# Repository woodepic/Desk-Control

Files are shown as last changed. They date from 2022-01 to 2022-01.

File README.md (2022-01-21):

# Desk-Control

This is a re-upload of an older project, as I didn't use github at the time. This project spanned July 2020 - August 2020. I am happy to report that it is still working perfectly to this day! (January 2022)

I personally don't enjoy having any form of light when I try to sleep. This would normally mean that I need to unplug my digital clock, monitors, etc on my desk. This causes wear on connectors, is time consuming, and certainly not elegant. To solve this problem, I created a simple relay-based PCB to toggle power on/off for various devices on my desk, and I use a simple button interface to control this. 

I also utilized an arduino to allow for smart control logic of the buttons, backlights, and relay timing. "Smart" features include a fade on/off animation in the buttons' backlights, minimum time between toggles (to allow devices to fully boot before power is cut to them), and more. The PCB uses transistor-switched 12v power to allow for a PWM signal to control the buttons' backlights, optocouplers for relay isolation protection, as well as a basic power supply. 

See below for images of the project. The far right button toggles the clock, and the middle button toggles the in-desk touch monitor:

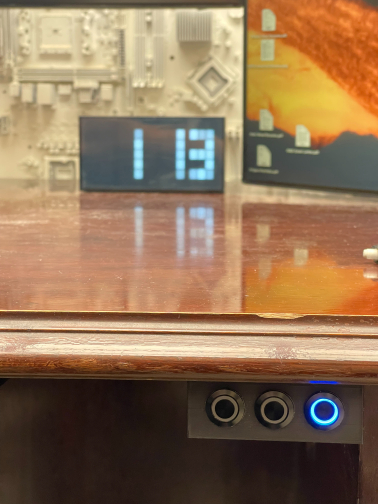
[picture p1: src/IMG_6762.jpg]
Button 3 toggles clock
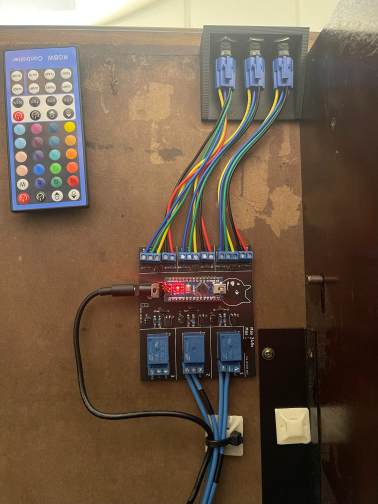
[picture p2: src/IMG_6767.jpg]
Underside view of buttons & PCB
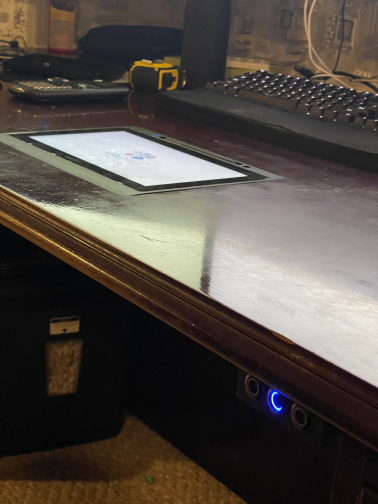
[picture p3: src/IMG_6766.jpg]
Button 2 toggles in-desk touch monitor


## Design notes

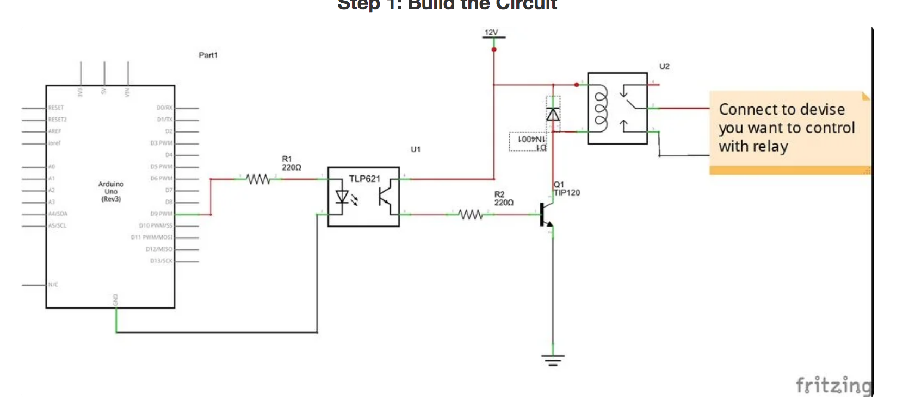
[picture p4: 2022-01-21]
PCB/Relays/Schematic.png

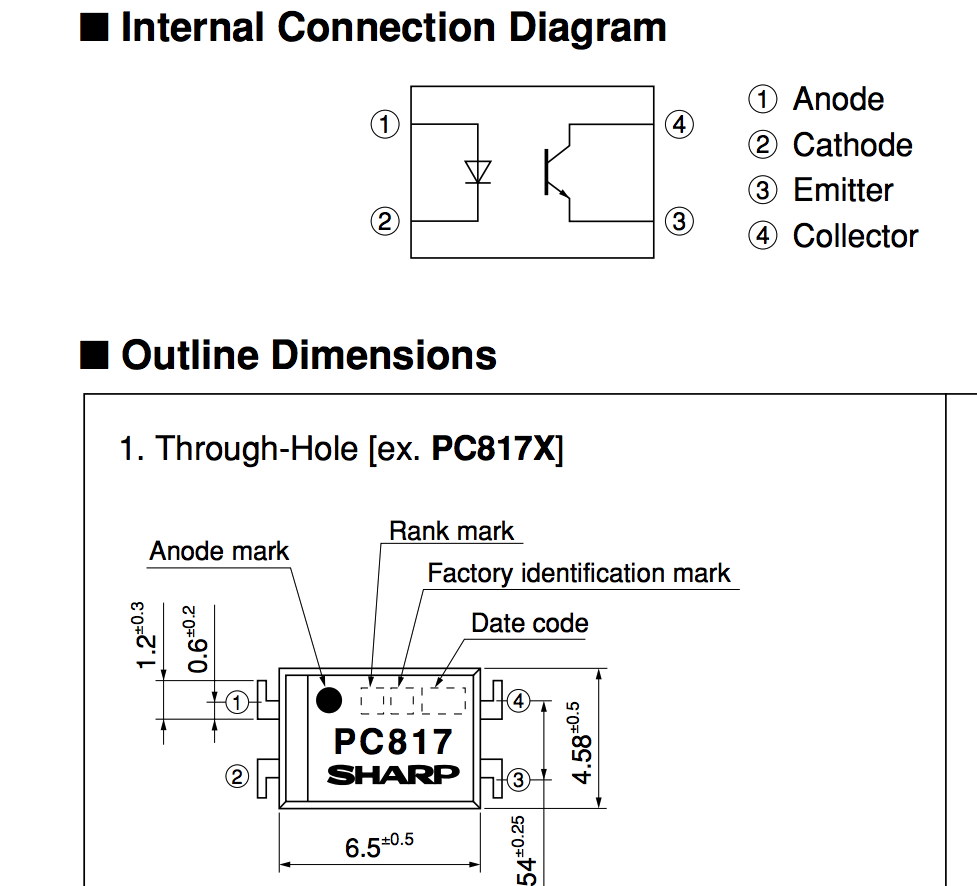
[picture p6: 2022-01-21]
PCB/Relays/Optocoupler Pinout.png

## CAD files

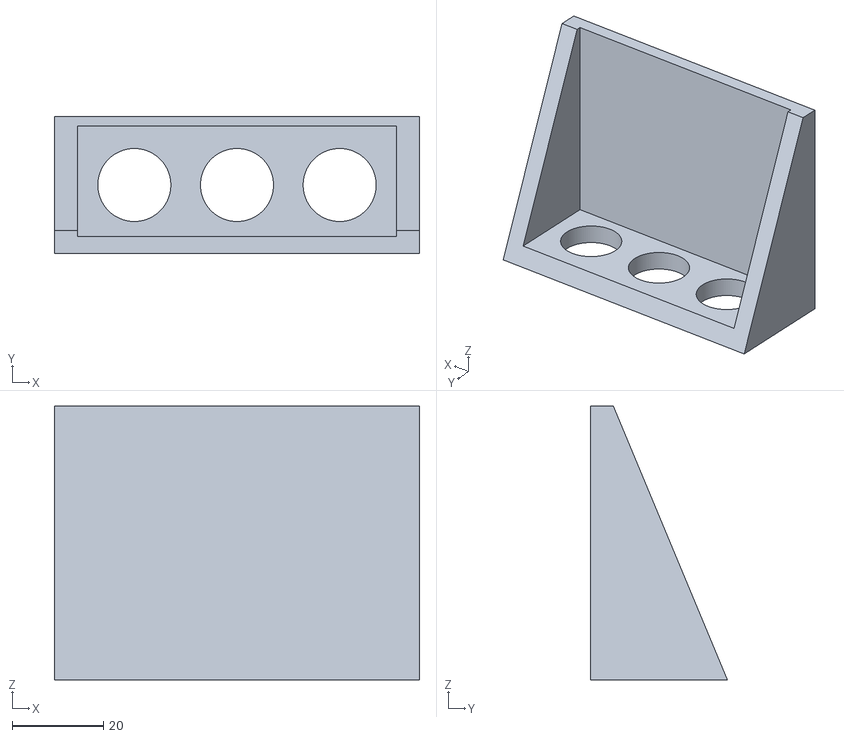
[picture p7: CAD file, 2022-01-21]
Desk Mount/V1.0skp.stl
80.0 x 30.0 x 60.0

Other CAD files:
Desk Mount/V1.0skp.skp

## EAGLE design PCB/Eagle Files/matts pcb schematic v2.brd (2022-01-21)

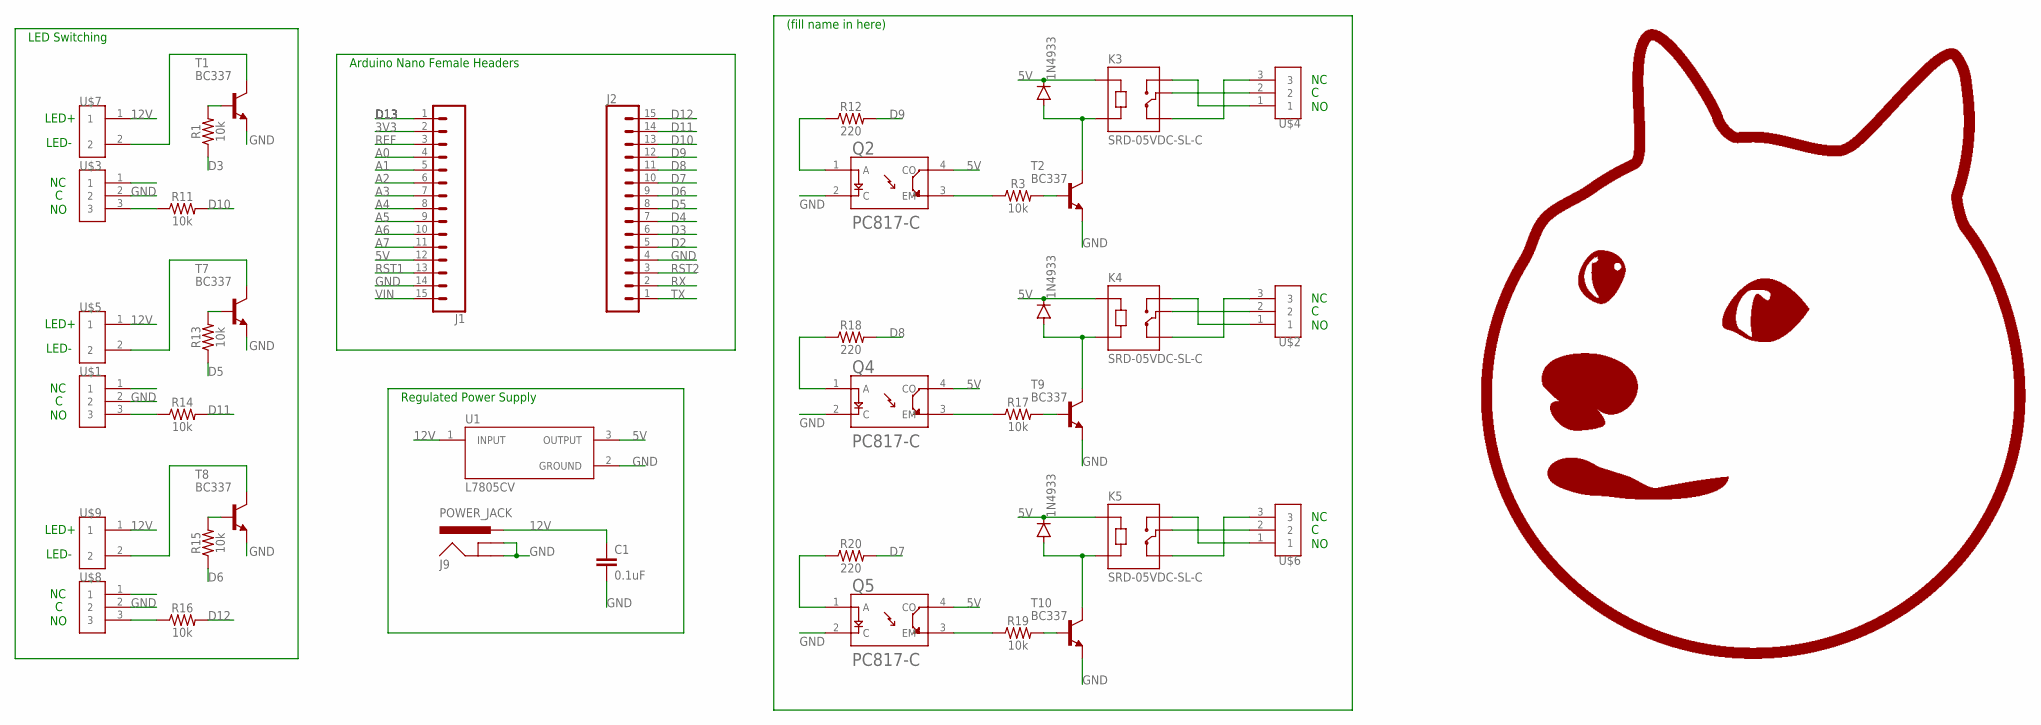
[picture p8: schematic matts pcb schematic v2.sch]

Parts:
C1: 0.1uF; CAP-PTH-SMALL-KIT
D1, D4, D5: 1N4933; DO41-10
J1, J2: CONN_15; 1X15
J9: POWER_JACK; POWER_JACK_PTH
K3, K4, K5: SRD-05VDC-SL-C; RELAY_SRD-05VDC-SL-C
Q2, Q4, Q5: PC817-C; DIP762W50P254L508H350Q4
R1, R3, R11, R13, R14, R15, R16, R17, R19: 10k; AXIAL-0.3
R12, R18, R20: 220; AXIAL-0.3
T1, T2, T7, T8, T9, T10: BC337; TO92
U1: L7805CV; TO255P1040X460X1968-3
U$1, U$2, U$3, U$4, U$6, U$8: 3PIN_0.2PITCH_SCREW_TERMINAL
U$5, U$7, U$9: 2PIN_0.2PITCH_SCREW_TERMINAL
U$10: DANK_DOGE

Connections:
3V3: J1.2
5V: D1.C, D4.C, D5.C, J1.12, K3.A1, K4.A1, K5.A1, Q2.4 (CO), Q4.4 (CO), Q5.4 (CO), U1.3 (OUTPUT)
12V: C1.1, J9.PWR, U1.1 (INPUT), U$5.1, U$7.1, U$9.1
A0: J1.4
A1: J1.5
A2: J1.6
A3: J1.7
A4: J1.8
A5: J1.9
A6: J1.10
A7: J1.11
D2: J2.5
D3: J2.6, R1.P$1 (1)
D4: J2.7
D5: J2.8, R13.P$1 (1)
D6: J2.9, R15.P$1 (1)
D7: J2.10, R20.P$2 (2)
D8: J2.11, R18.P$2 (2)
D9: J2.12, R12.P$2 (2)
D10: J2.13, R11.P$2 (2)
D11: J2.14, R14.P$2 (2)
D12: J2.15, R16.P$2 (2)
D13: J1.1
GND: C1.2, J1.14, J2.4, J9.GND, J9.GNDBREAK, Q2.2 (C), Q4.2 (C), Q5.2 (C), T1.1 (E), T2.1 (E), T7.1 (E), T8.1 (E), T9.1 (E), T10.1 (E), U1.2 (GROUND), U$1.2, U$3.2, U$8.2
unnamed: K3.COM, U$4.2
unnamed: R14.P$1 (1), U$1.3
unnamed: T1.3 (C), U$7.2
unnamed: T7.3 (C), U$5.2
unnamed: R1.P$2 (2), T1.2 (B)
unnamed: R13.P$2 (2), T7.2 (B)
unnamed: R11.P$1 (1), U$3.3
unnamed: R16.P$1 (1), U$8.3
unnamed: T8.3 (C), U$9.2
unnamed: R15.P$2 (2), T8.2 (B)
unnamed: K3.NO, U$4.1
unnamed: K3.NC, U$4.3
unnamed: D1.A, K3.A2, T2.3 (C)
unnamed: R3.P$2 (2), T2.2 (B)
unnamed: Q2.3 (EM), R3.P$1 (1)
unnamed: Q2.1 (A), R12.P$1 (1)
unnamed: K4.COM, U$2.2
unnamed: K4.NO, U$2.1
unnamed: K4.NC, U$2.3
unnamed: D4.A, K4.A2, T9.3 (C)
unnamed: Q4.1 (A), R18.P$1 (1)
unnamed: R17.P$2 (2), T9.2 (B)
unnamed: Q4.3 (EM), R17.P$1 (1)
unnamed: K5.COM, U$6.2
unnamed: K5.NO, U$6.1
unnamed: K5.NC, U$6.3
unnamed: D5.A, K5.A2, T10.3 (C)
unnamed: Q5.1 (A), R20.P$1 (1)
unnamed: R19.P$2 (2), T10.2 (B)
unnamed: Q5.3 (EM), R19.P$1 (1)
REF: J1.3
RST1: J1.13
RST2: J2.3
RX: J2.2
TX: J2.1
VIN: J1.15

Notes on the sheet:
Arduino Nano Female Headers
LED+
LED-
Regulated Power Supply
LED Switching
(fill name in here)

Board: 2 copper layers, 42 parts (0 on the bottom side), 42 nets, no tracks yet.

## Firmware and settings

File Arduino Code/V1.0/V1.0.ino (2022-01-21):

int but1 = 12;
int but2 = 11;
int but3 = 10;
int led1 = 5;
int led2 = 3;
int led3 = 6;
int rly1 = 9;
int rly2 = 7;
int rly3 = 8;

#define minTimeRly1 1000 //The minimum number of ms that the relay for channel 1 stays on and off. (to prevent turning on
// and off like 10 times a second, which is bad for the electronics that are connected. For example, the clock may have a smaller min time than a monitor.)
#define minTimeRly2 30000
#define minTimeRly3 1000
#define fadeSpeed 30 //in percent
#define targetBrightness 255 //The brigness of leds when on. a number from 0-255. 0 is off, 255 is full on.
#define offBrightness 0 //The brigness of leds when off. a number from 0-255. 0 is off, 255 is full on.


enum stateEnum {
  on,
  turningOn,
  off,
  turningOff
};

class LEDcontroller {
  public:
    int selectedLED;
    stateEnum state;
    unsigned long long int lastOnTime;
    unsigned long long int lastOffTime;
    unsigned long long int lastIncreaseTime;
    unsigned long long int lastDecreaseTime;
    int brightness;



    LEDcontroller(int ledNum) {
      switch(ledNum) {
        case 1:
          selectedLED = led1;
          break;
        case 2:
          selectedLED = led2;
          break;
        case 3:
          selectedLED = led3;
          break;
      }

      digitalWrite(selectedLED, LOW);
      brightness = offBrightness;
      state = off;
      lastOffTime = millis();
    }

    void applyBrightness() {
      analogWrite(selectedLED, brightness);
    }

    void increaseBrightness() {
      //imcrease brightness
      brightness += 1;
    }

    void decreaseBrightness() {
      brightness -= 1;
    }
};






LEDcontroller LED1(1);
LEDcontroller LED2(2);
LEDcontroller LED3(3);
int fadeInterval;

void setup() {
  Serial.begin(9600);
  pinMode(but1, INPUT_PULLUP); //channel 1 button
  pinMode(but2, INPUT_PULLUP); //channel 2 button
  pinMode(but3, INPUT_PULLUP); //channel 3 button

  pinMode(led1, OUTPUT); //channel 1 LED
  pinMode(led2, OUTPUT); //channel 2 LED
  pinMode(led3, OUTPUT); //channel 3 LED

  pinMode(rly1, OUTPUT); //cahnnel 1 out
  pinMode(rly2, OUTPUT);; //channel 2 out
  pinMode(rly3, OUTPUT); //channel 3 out

  fadeInterval = map(fadeSpeed, 0, 100, 10, 0);

  delay(1000); //prevents premature execution of loop()
}

void loop() {

//Turn on led1 and rly1 when but1 is pressed.
  LED1.applyBrightness();
  if ((LED1.state == off) && (digitalRead(but1) == LOW) && ((millis() - LED1.lastOffTime) > minTimeRly1)) {
    //if the led was off more more than 1s and you press the button...
    //This is essentially the criteria that decides we now process to fading on the button.

    digitalWrite(rly1, HIGH); //turn on relay now (before led fully turns on)
    //keep track of parameters.
    LED1.state = turningOn;
  }

  if (LED1.state == turningOn){
    //increase brightness at a given interval until we are at our decided brightness level

    if ((LED1.brightness < targetBrightness) && ((millis() - LED1.lastIncreaseTime) > fadeInterval)){
      LED1.increaseBrightness();
      LED1.lastIncreaseTime = millis();
    }

    else if (LED1.brightness == targetBrightness) {
      //Once at full brightness
      LED1.state = on;
      LED1.lastOnTime = millis();
    }
  }

  if ((LED1.state == on) && (digitalRead(but1) == HIGH) && ((millis() - LED1.lastOnTime) > minTimeRly1)) {
    //if the led was on more more than 1s and you press the button...
    //This is essentially the criteria that decides we now process to fading off the button.

    digitalWrite(rly1, LOW); //turn off relay now (before led fully turns off)
    //keep track of parameters.
    LED1.state = turningOff;
  }

  if (LED1.state == turningOff){
    //increase brightness at a given interval until we are at our decided brightness level

    if ((LED1.brightness > offBrightness) && ((millis() - LED1.lastDecreaseTime) > fadeInterval)){
      LED1.decreaseBrightness();
      LED1.lastDecreaseTime = millis();
    }

    else if (LED1.brightness == offBrightness) {
      //Once at full brightness
      LED1.state = off;
      LED1.lastOffTime = millis();
    }
  }

//Turn on led2 and rly2 when but2 is pressed.
  LED2.applyBrightness();
  if ((LED2.state == off) && (digitalRead(but2) == LOW) && ((millis() - LED2.lastOffTime) > minTimeRly2)) {
    //if the led was off more more than 1s and you press the button...
    //This is essentially the criteria that decides we now process to fading on the button.

    digitalWrite(rly2, HIGH); //turn on relay now (before led fully turns on)
    //keep track of parameters.
    LED2.state = turningOn;
  }

  if (LED2.state == turningOn){
    //increase brightness at a given interval until we are at our decided brightness level

    if ((LED2.brightness < targetBrightness) && ((millis() - LED2.lastIncreaseTime) > fadeInterval)){
      LED2.increaseBrightness();
      LED2.lastIncreaseTime = millis();
    }

    else if (LED2.brightness == targetBrightness) {
      //Once at full brightness
      LED2.state = on;
      LED2.lastOnTime = millis();
    }
  }

  if ((LED2.state == on) && (digitalRead(but2) == HIGH) && ((millis() - LED2.lastOnTime) > minTimeRly2)) {
    //if the led was on more more than 1s and you press the button...
    //This is essentially the criteria that decides we now process to fading off the button.

    digitalWrite(rly2, LOW); //turn off relay now (before led fully turns off)
    //keep track of parameters.
    LED2.state = turningOff;
  }

  if (LED2.state == turningOff){
    //increase brightness at a given interval until we are at our decided brightness level

    if ((LED2.brightness > offBrightness) && ((millis() - LED2.lastDecreaseTime) > fadeInterval)){
      LED2.decreaseBrightness();
      LED2.lastDecreaseTime = millis();
    }

    else if (LED2.brightness == offBrightness) {
      //Once at full brightness
      LED2.state = off;
      LED2.lastOffTime = millis();
    }
  }

//Turn on led3 and rly3 when but3 is pressed.
  LED3.applyBrightness();
  if ((LED3.state == off) && (digitalRead(but3) == LOW) && ((millis() - LED3.lastOffTime) > minTimeRly3)) {
    //if the led was off more more than 1s and you press the button...
    //This is essentially the criteria that decides we now process to fading on the button.

    digitalWrite(rly3, HIGH); //turn on relay now (before led fully turns on)
    //keep track of parameters.
    LED3.state = turningOn;
  }

  if (LED3.state == turningOn){
    //increase brightness at a given interval until we are at our decided brightness level

    if ((LED3.brightness < targetBrightness) && ((millis() - LED3.lastIncreaseTime) > fadeInterval)){
      LED3.increaseBrightness();
      LED3.lastIncreaseTime = millis();
    }

    else if (LED3.brightness == targetBrightness) {
      //Once at full brightness
      LED3.state = on;
      LED3.lastOnTime = millis();
    }
  }

  if ((LED3.state == on) && (digitalRead(but3) == HIGH) && ((millis() - LED3.lastOnTime) > minTimeRly3)) {
    //if the led was on more more than 1s and you press the button...
    //This is essentially the criteria that decides we now process to fading off the button.

    digitalWrite(rly3, LOW); //turn off relay now (before led fully turns off)
    //keep track of parameters.
    LED3.state = turningOff;
  }

  if (LED3.state == turningOff){
    //increase brightness at a given interval until we are at our decided brightness level

    if ((LED3.brightness > offBrightness) && ((millis() - LED3.lastDecreaseTime) > fadeInterval)){
      LED3.decreaseBrightness();
      LED3.lastDecreaseTime = millis();
    }

    else if (LED3.brightness == offBrightness) {
      //Once at full brightness
      LED3.state = off;
      LED3.lastOffTime = millis();
    }
  }
  

}

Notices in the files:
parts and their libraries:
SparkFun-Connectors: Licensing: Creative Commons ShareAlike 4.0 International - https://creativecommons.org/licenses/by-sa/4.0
